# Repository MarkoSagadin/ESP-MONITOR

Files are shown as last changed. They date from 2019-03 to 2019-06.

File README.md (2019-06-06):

# ESP-MONITOR
## ESP8266 based current consumption and serial monitor with Grafana visualization on Raspberry 3 with Node-Red and InfluxDB integration

**ESP-MONITOR** was developed as a student project with help of **IRNAS**, Institute for development of advanced applied systems. You can learn more about them on their [website](http://www.irnas.eu) or [GitHub](https://github.com/IRNAS) page.

Part of the **ESP-MONITOR** project is also repository for Balena multicontainer setup. It can be found [here](https://github.com/SkobecSlo/ESP-MONITOR_balena_setup).
     
### Content
- [Introduction](#Introduction)
- [Preparing the development enviroment](#Preparing-development-enviroment)
- [Overview and setup of ESP-MONITOR](#Overview-and-setup-of-ESP-MONITOR)
- [Setup Raspberry Pi with Balena ](#Setup-raspberry-pi-with-Balena) 
- [Push code to Raspberry](#Push-Raspberry-with-code)
- [Create Influxdb database](#Create-Influxdb-database)
- [Setup Node-Red](#Setup-Node-Red)
- [Setup Grafana](#Setup-Grafana)
- [Resources](#Resources)

###  Introduction 
Often we want to monitor current consumption of our devices. We usually want to do this over a longer periods of time. Maybe we are unsure how some tasks will impact our current consumption and also if our devices really go into sleep mode for periods of time that we intend. At the same time we migh want to catch any serial debug data that our device outputs.

### Perfect job for ESP-MONITOR!
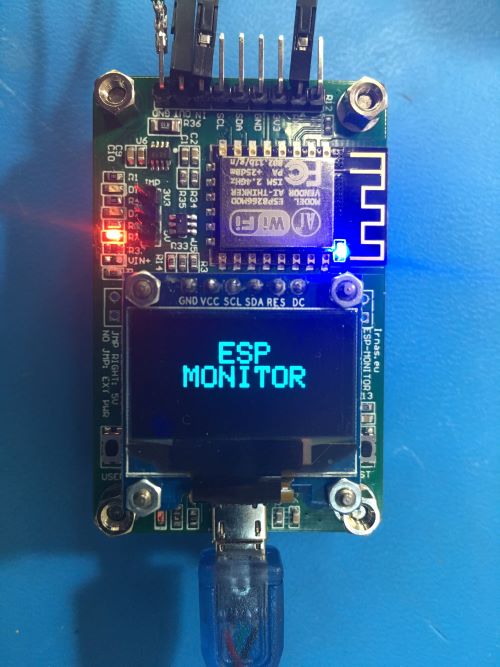
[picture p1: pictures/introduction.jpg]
Introduction


**ESP-MONITOR** is a device that is measuring current consumption and voltage on the device you are monitoring. At the same time it is listening for messages over UART serial connection.
When enough samples are made, we use them to calculate maximum, minimum and average values and standard deviation. 
This values and any received serial messages are then send as a **MQTT** message  to our Raspberry which with help of **Node-RED** parses and prepares our messages to save them into **Influxdb** database.
**Grafana** is then reading the database and displaying the data. 
It is possible to have several of **ESP-MONITOR** devices devices running at the same time and displaying the collected data in **Grafana**. 
That way we can see if several of our monitored devices are behaving as expected. 

###  Preparing the development environment

Download or clone the whole repository from Github.

Use command: `git clone https://github.com/SkobecSlo/ESP-MONITOR.git` in git bash. 

To compile and upload code to our ESP-MONITOR we will need [Visual Studio Code](https://code.visualstudio.com) with **PlatformIO** extension. 
**Visual Studio Code** is a source-code editor developed by Microsoft for Windows, Linux and macOS. It includes support for debugging, embedded Git control, syntax highlighting, intelligent code completion, snippets, and code refactoring.
**PlatformIO** is an open source ecosystem for IoT development. It enables you to quickly install all tools, compilers, basically everything that is needed to quickly start programming your favorite device.
After you install Visual Studio Code, you head to **Extensions** tab (found on left sidebar) and search for **PlatformIO IDE
** in Marketplace search bar. Click install and reload Visual Studio Code to enable newly added plugin. PlatformIO's logo will be added to the left sidebar. 

There are several Arduino libraries that ESP-MONITOR depends on which will have to be installed through PlatformIO. 
Go to PlatformIO -> PIO Home -> Libraries. Search and install following libraries:
- Adafruit_SSD1306 by Adafruit
- Adafruit_GFX by Adafruit
- PubSubClient by Nick O'Leary
- INA219 by DeCristofaro John (when clicked you will see by by gandy92, that is ok)

Adafruits libraries are used for interacting with OLED display over I2C, PuBSubClient is used for MQTT comunication and INA219 is used for interacting with INA219 current monitor over I2C. 

After all libraries are installed go to *File -> Add File to Workspace* and select folder ESP-MONITOR_CODE. To check if everything is ok build the code by clicking **PlatformIO: Build** button on the left side of blue bar at the bottom of Visual Studio Code. 

###  Overview and setup of ESP-MONITOR
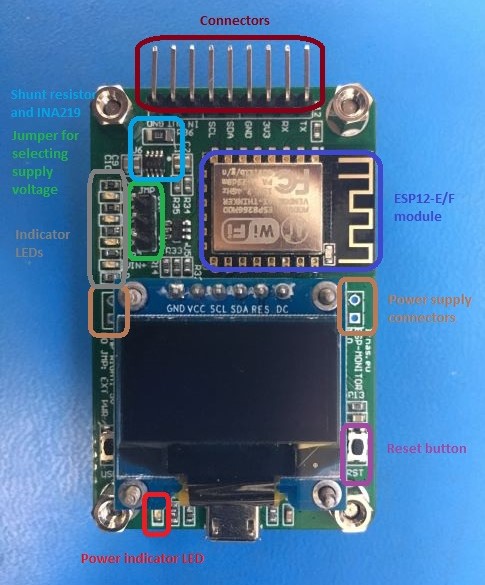
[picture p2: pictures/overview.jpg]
Overview


The heart of ESP-MONITOR is Espressif ESP8266 chip running Arduino enviroment. Code is uploaded over USB connector with help of USB to Serial converter CP2102. The upload setup is similiar to the setup that is used on **NodeMcu** and official development kits boards by **Espressif**. 

#### Short description of PCB elements
**Connectors:** At the top of the board you can find RX pin on which the monitor listens for serial data, TX pin is also exposed for those that want to add extra functionality to the module for comunication with monitored device. Exposed are also 3V3 and GND as well the I2C pins. These can be used to add any extra functionality to the **ESP-MONITOR**. Finally there are also currentmonitor pins IN and OUT. Their role is described below. 

**Power supply connectors:** They are used for chaining several of **ESP-MONITORs** together so that they run from the same power supply. 

**Power indicator LED:** If **ESP-MONITOR** is connected to power supply led will be on, simple as that.  

**Reset buton:** It resets ESP12-E/F module.  

**User button:** It clears flash memory in case if user does not want to use current network which is still reachable. 

**Jumper:** Can be used to connect 3V3 or 5V to the IN pin internally, so that monitored device can function directly from **ESP-MONITOR**. Detailed explantation can be found below. 

**Indicator LEDs:** LED D1 and D2 are controled by ESP module, D1 blinks everytime when current and voltage measuremnts are sent over mqtt. RX LED is connected directly to RX pin. VIN+ LED is connected to IN pin. **WARNING!!** If using higher supply voltages than 5V on IN pin, either **desolder** VIN+ LED off the board or change current limiting resistor R3, otherwise there is gonna be some burning smell.  

#### OLED display configuration

**ESP-MONITOR** is designed in that way that you can connected three different OLED displays (that are usually found on Ebay or AliExpress) to it. The difference is ony in the setup of 0 ohm resistors that are labeled with letters A, B and C under the display. Follow the bottom instructions to determine which resistors are soldered and which ones not, depending on the version of the OLED display.

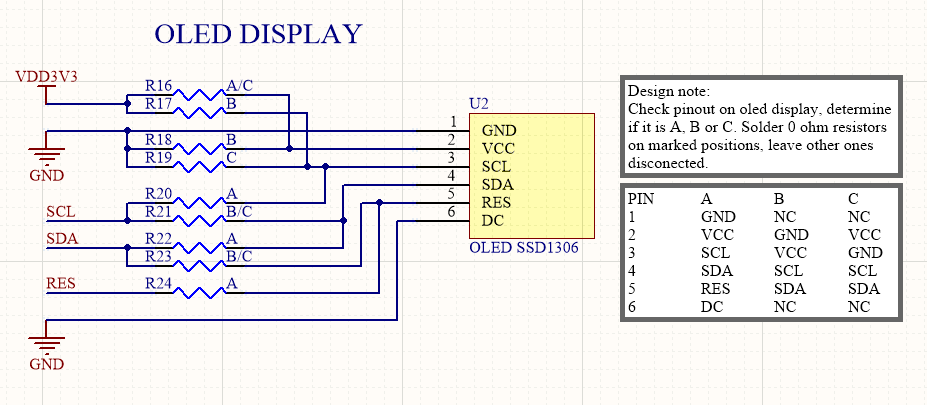
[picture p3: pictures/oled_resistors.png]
oled_resistors


#### Serial data connection
To listen to your serial data of monitored device connect TX output from your device to the RX pin of **ESP-MONITOR**.

#### Current measuring

There are two ways to setup current measuring with **ESP-MONITOR**, either measured device is self powered or we power it from **ESP-MONITOR**.

**Self powered setup**

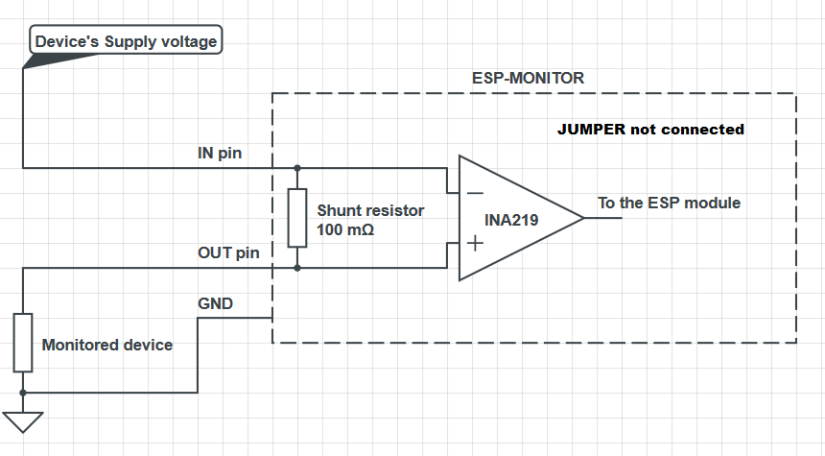
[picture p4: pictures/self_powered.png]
Self_powered


Power is supplied only from monitored device, before connecting IN and OUT pins first connect GND. Jumper is not connected!

**ESP-MONITOR powered setup**

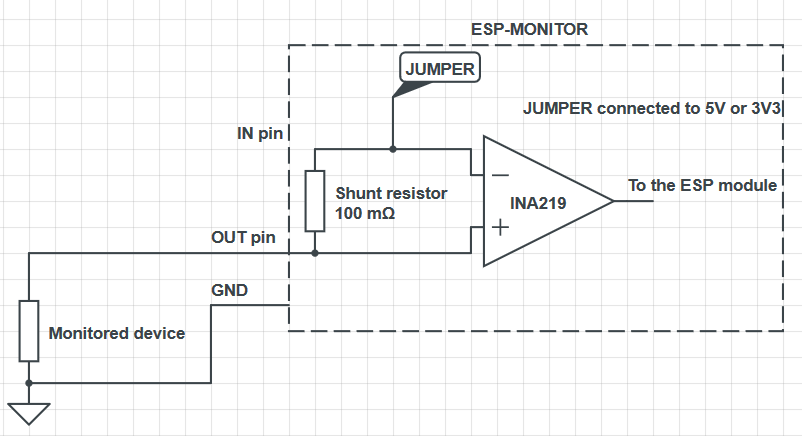
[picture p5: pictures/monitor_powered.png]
monitor_powered


**ESP-MONITOR** is supplying the power. Jumper is connected to 3V3 or 5V. To connect either of this voltages to IN line we have to enable it with Power Cycle pin in Node-Red dashboard. This will be described below.

### Uploading the code and setting the WIFI connection

1. Connect **ESP-MONITOR** with USB to computer and upload the code by clicking **PlatformIO: Upload** button on the left side of blue bar at the bottom of Visual Studio Code. 
2. **ESP-MONITOR's** display should turn on and greet you.
3. Follow instructions on the display: connect with the phone or PC to WIFI network ESP-MONITOR (password is also ESP-MONITOR).
4. Open browser and write IP address 192.168.4.1 in URL field. You will see all nearby wifi networks. Chose one which **ESP-MONITOR** and **Raspberry Pi** will use and connect to it.
5. Reset the module with RESET button, **ESP-MONITOR** should connect to the chosen network. If not, repeat the process. 
  
###  Setup Raspberry Pi with Balena

Balena is an infrastructure for developing, deploying, and managing connected devices at scale. It basically enables you to take an embedded device (or devices) with Linux OS and control or update their firmware over air. 

Steps to get Raspberry Pi running with Balena
1. Create an account on [Balena](https://www.balena.io)
2. Follow instructions on Balena's get started [web page](https://www.balena.io/docs/learn/getting-started/raspberrypi3/nodejs/) untill the start of chapter **Deploy Code**.
3. Make sure that you download the correct and latest image for Raspberry Pi 3.
4. Make sure that under Network option you check Wifi + Ethernet and that Wifi ssid and passphrase are the same as the one you used to connect **ESP-MONITOR** to.   

###  Push code to Raspberry 

Open git bash in folder of your choice and write:
1. `git clone https://github.com/SkobecSlo/ESP-MONITOR_balena_setup.git`
2. `cd ESP-MONITOR_balena_setup`
3. Go to your Balena application dashboard and click copy to clip board button and paste it into git bash
git_remote
4. `git push balena master`

The last command will upload the whole repository first to the Balena servers which will compile them and then upload them to the Raspberry. In case of successfull event you will see Balena Unicorn in git bash. 

###  Create Influx database

Before continuing to our Node-Red flows, we have to setup our database in which we will be saving data into. 
Go to the application dashboard of your device and click its name. This link will take you to the dashboard of that specific device. Here you can see status of your device, if it is online, offline, updating, ect. 
After making sure that device is updated with our code click inside Terminal window a **select a target** button and select **influxdb** option. This action will make a SHH connection to our Influxdb container. Type `Influxdb` and then following command: `create database Monitor`

This will create exactly what it says. Use exactly that case sensitive name, as it is the name that **Grafana** expects. Close the connection. 

###  Setup Node-Red  

1. Enable public device URL and click blue button that will appear next to it.
2. This will take you to the **Grafana** login page, which we dont need yet.
3. In Url box of the browser delete /login from the end of URL and replace it with /node-red
4. This will take you to the configuration page of **Node-Red**
5. Username and password are **admin**
6. Locate node-red-flow.txt file in node-red-setup folder
7. Copy its content and locate in Node-Red *Menu -> Import -> Clipboard* option and paste it there.

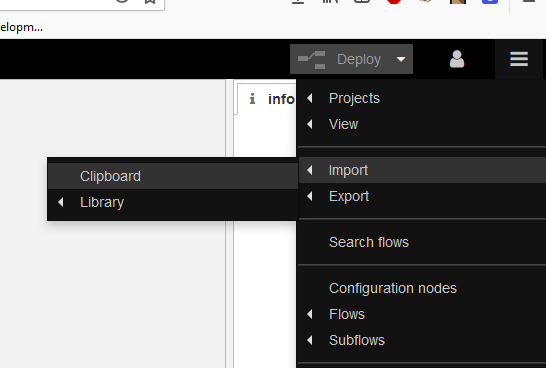
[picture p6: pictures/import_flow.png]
import_flow


This is a basic default flow configuration. There are some parameters that are device specific and need to be changed to work with your Raspberry Pi:
- Click one of the purple mqtt nodes in Node-Red and make sure that the IP address of the server is the same as the IP address of your device which can be found on device's Balena dashboard. Port stays 1883. Check all other purple nodes if they have correct setup.

That is it, you can now click Deploy button at top. Mqtt nodes should have green dot with connected label next to them. 

If you add to the end of public url **/node-red/ui** you will arrive at Node-Red dashboard, where you can see most recent serial output, most recent raw measurement and a Power Cycle switch which will control voltage on IN pin if jumper is connected to either 3V3 or 5V. 

###  Setup Grafana  

1. Go to your public device url now and login into Grafana with username: **admin** and password **admin**. 
2. Click *Gear icon -> Data sources* 
3. Click big icon with Monitor title and Influxdb logo.
4. All details should be filled in, scroll down and click save and test button. If everything is ok you will get conformation message.
5. Go back to main menu and click *Home* button and under general choose *Current consumption*.  

Now you are in the main dashboard that is showing all data that **ESP-MONITOR** is collecting. To make data actually appear you have to setup each one of the windows to your deviceID tag that is specific for each **ESP-MONITOR**. 
1. Click at the top of one of the windows and chose edit option. Click one of the lines under the Metrics tab and click field next to deviceID equal sign.
2. It should show you the id that is showed on OLED display of **ESP-MONITOR**, select it.
3. Do this for each line, for each graph, table in Grafana dashboard. 
4. You should see data that **ESP-MONITOR** collected.
  
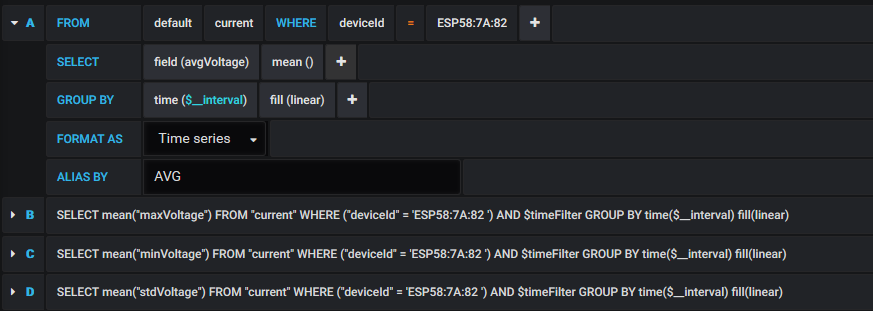
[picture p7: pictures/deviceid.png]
deviceid

#### Specific strings setup

Node-Red is already saving all serial data into InfluxDB and Grafan is already displaying them as timetable. If you want to monitor for specific string and represent it in a graph do following:
1. Navigate to Node-Red and click on Messages node
2. Here you can add specific string that you are looking for 
3. Select **contains** option and in the field write your string
4. You can add more of them by clicking add button on the bottom, this will add more outputs to the node.
5. Each output fill have to go through separate **Notification string** node before going into **Specific strings** INfluxdb node. 
6. Modify this field in each separate **Notification string** node to your liking, it can be the same as the specific stirng you are searching for. Deploy changes 
7. These fields are tags that Grafana uses to present data. 
8. Go to Grafana and create or edit existing graph.
9. Metrics tab should look something like picture below, you have to change devices id to yours and also notificationField to the string that you used in Node-Red.

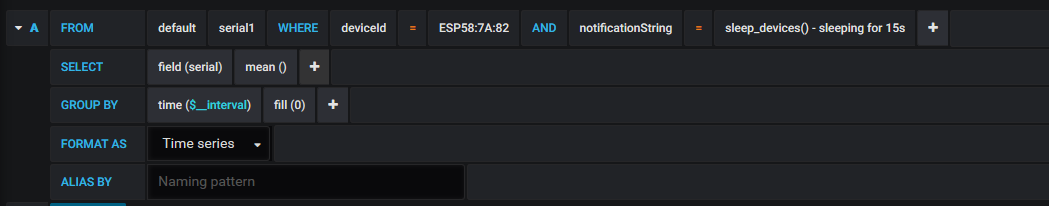
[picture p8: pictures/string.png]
string


###  Resources 

Here are some resources that helped me on my way of developing the project:
- [ESP-LINK](https://github.com/jeelabs/esp-link) 
- [Balena Sense](https://github.com/balena-io-playground/balena-sensehat-example)
- [Multicontainer Balena example with 8 containers](https://github.com/janvda/balena-node-red-mqtt-nginx-TIG-stack)
- [Provisioned dashboards for Grafana](https://ops.tips/blog/initialize-grafana-with-preconfigured-dashboards)
- [Andreas Spiess's video on Node-Red, Influxdb and Grafana](https://www.youtube.com/watch?v=JdV4x925au0)

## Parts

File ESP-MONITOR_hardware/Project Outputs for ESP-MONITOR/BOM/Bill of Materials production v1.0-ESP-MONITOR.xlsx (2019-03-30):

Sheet: Part List Report
 | Component list |  |  | ESP-MONITOR
 | Source Data From: | ESP-MONITOR.PrjPCB |  |  | Contact:
 | Project: | ESP-MONITOR.PrjPCB
 | Variant: | None |  |  |  |  |  |  | IRNAS
 | Report Date: | 2019-12-03 | 10:47:00 |  |  |  |  |  | www.irnas.eu
 | Print Date: | 2019-03-12 | 10:48:11
# | Manufacturer Part Number 1 | Manufacturer 1 | Description | Footprint | Designator | Quantity | Supplier 1 | Supplier Part Number 1 | Supplier Order Qty 1 | Supplier Stock 1 | Supplier Unit Price 1 | Supplier Subtotal 1 | Supplier Currency 1
1 | GRM188R61H105KAALD | Murata | MURATA - GRM188R61H105KAALD - CAP, MLCC, X5R, 1UF, 50V, 0603 | CAP0603 | C1, C9 | 2 | Farnell | 1845736 | 10 | 0 | 0.35 | 3.51 | GBP
2 | GRM188R71C104KA01J | Murata | MURATA - GRM188R71C104KA01J - CAP, MLCC, X7R, 0.1UF, 16V, 0603 | CAP0603 | C2, C3, C8, C10 | 4 | Farnell | 2688519 | 10 | 0 | 0.02 | 0.21 | EUR
3 | CGA4J1X5R1C106K125AC | TDK | TDK - CGA4J1X5R1C106K125AC - CAP, MLCC, X5R, 10UF, 16V, 0805 | CAP0805 | C4, C5, C7 | 3 | Farnell | 2210948RL | 150 | 0 | 0.24 | 36.00 | GBP
4 | MCSH18B101K500CT | Multicomp | MULTICOMP MCSH18B101K500CT SMD Multilayer Ceramic Capacitor, MCSH Series, 100 pF, 10%, X7R, 50 V, 0603 [1608 Metric] | CAP0603 | C6 | 1 | Farnell | 1856366 | 10 | 18461 | 0.05 | 0.49 | GBP
5 |  |  |  | microUSB-CHINA | CON2 | 1
6 | HSMS-C190 | Broadcom | BROADCOM LIMITED - HSMS-C190 - LED, RED, 10MCD, 626NM | LED0603 | D1, D2, D5, RX, VIN+ | 5 | Farnell | 2497356 | 10 | 0 | 0.12 | 1.24 | GBP
7 | MBR120VLSFT3G | ON Semiconductor | ON SEMICONDUCTOR - MBR120VLSFT3G - SCHOTTKY RECT, 1A, 20V, SOD123 | SOD123 | D4 | 1 | Farnell | 2533227 | 5 | 60691 | 0.26 | 1.31 | GBP
8 | 0603L035YR | Littelfuse | LITTELFUSE - 0603L035YR - RESETTABLE FUSE, PTC, 40A, 6V, 0605 | FUSE0603 | F3 | 1 | Farnell | 1832099 | 10 | 3378 | 1.28 | 12.80 | GBP
9 |  |  | Jumper_1x3 | Jumper_1x3_2.54MM | J4 | 1
10 |  |  | Header, 2-Pin | HDR1X2 | P1, P3, P4 | 3
11 |  |  | Header, 4-Pin | HDR1X4 | P2 | 1
12 |  |  | Header, 3-Pin | HDR1X3 | P5 | 1
13 | MCMR06X471JTL | Multicomp | MULTICOMP - MCMR06X471 JTL - RES, CERAMIC, 470R, 5%, 0.1W, 0603 | RES0603 | R1, R4, R8, R26, R37 | 5 | Farnell | 2073513 | 10 | 0 | 0.01 | 0.06 | EUR
14 | MCMR06X4701FTL | Multicomp | MULTICOMP - MCMR06X4701FTL - RES, CERAMIC, 4K7, 1%, 0.1W, 0603 | RES0603 | R2, R3 | 2 | Farnell | 2073509 | 10 | 27151 | 0.01 | 0.09 | GBP
15 | CR0603-J/-000ELF | Bourns | BOURNS - CR0603-J/-000ELF - RES, THICK FILM, 0R, 5%, 0.1W, 0603 | RES0603 | R5, R6, R16, R17, R18, R19, R20, R21, R22, R23, R24, R25, R27 | 13 | Farnell | 2008343 | 26 | 46345 | 0.01 | 0.31 | GBP
16 | MCMR06X103JTL | Multicomp | MULTICOMP - MCMR06X103 JTL - RES, CERAMIC, 10K, 5%, 0.1W, 0603 | RES0603 | R7, R9, R10, R11, R12, R13, R14, R15, R31 | 9 | Farnell | 2073356 | 18 | 0 | 0.01 | 0.14 | EUR
17 | MCWR06X27R0FTL | Multicomp | MULTICOMP MCWR06X27R0FTL Surface Mount Chip Resistor, Thick Film, MCWR Series, 27 ohm, 100 mW, 1%, 50 V | RES0603 | R28, R29 | 2 | Farnell | 2447316 | 10 | 108261 | 0.01 | 0.05 | GBP
18 | MC0.063W06031%1M | Multicomp | MULTICOMP - MC0063W060311M - RES, THICK FILM, 1M, 1%, 0.063W, 0603 | RES0603 | R30 | 1 | Farnell | 9330410 | 10 | 0 | 0.07 | 0.69 | GBP
19 | MCMR06X104JTL | Multicomp | MULTICOMP - MCMR06X104 JTL - RES, CERAMIC, 100K, 5%, 0.1W, 0603 | RES0603 | R32, R34 | 2 | Farnell | 2073357 | 10 | 49 | 0.01 | 0.07 | GBP
20 | MC0.063W06031%100R | Multicomp | MULTICOMP - MC0063W06031100R - RES, THICK FILM, 100R, 1%, 0.063W, 0603 | RES0603 | R33, R35 | 2 | Farnell | 9330364 | 10 | 0 | 0.04 | 0.36 | EUR
21 | TL2BR10FTE | TE Connectivity | TE CONNECTIVITY - TL2BR10FTE - RESISTOR, METAL , R10, 0.25W, 1%, 1206 | RES1206 | R36 | 1 | Farnell | 2330389 | 10 | 360 | 0.79 | 7.93 | GBP
22 |  |  | SWITCH TACTILE SPST-NO 0.05A 32V | Tactile button | RST, USER | 2 | C&K Components | 2845727
23 |  |  | ESP-12 Wi-Fi Module by AI-Thinker | ESP_12_E | U1 | 1
24 |  |  |  | OLED SSD1306 | U2 | 1
25 |  |  | NCP1117, NCV1117. 1.0 A Low-Dropout Positive Fixed and Adjustable Voltage Regulators | SOT-223 - 4con | U3 | 1
26 | CP2102N-A01-GQFN28 | Silicon Labs | SILICON LABS CP2102N-A01-GQFN28 Interface Bridges, USB to UART, 3 V, 3.6 V, QFN, 28 Pins, -40 C New | QFN50P500X500X80_HS-29N | U4 | 1 | Farnell | 2577279 | 2 | 0 | 1.46 | 2.92 | EUR
27 | DMG6602SVT | Diodes | DIODES INC. - DMG6602SVT - MOSFET, NP CH, , 30V, 3.4, ATSOT23 | TSOT26 | U5 | 1 | Farnell | 2061522 | 5 | 2033 | 0.24 | 1.20 | EUR
28 | INA219AIDCNR | Texas Instruments | 26V, Bi-Directional, High-Side, I2C Out Current/Power Monitor 8-SOT-23 -40 to 125 | SOT23-8 | U6 | 1 | Farnell | 2295989 | 2 | 13626 | 1.53 | 3.06 | GBP
29 |  |  | Surface mount NPN transistor, package SOT-23 | SMT_TRIODE_NPN | VT1, VT2 | 2
 |  |  |  |  |  | 71 |  |  | 328 |  |  | 72.4404
Approved |  |  |  | Notes
 |  |  |  | pcs: |  | 2 |  | Total |  | 72.4404 |  | EUR
 |  |  |  |  |  |  |  | Price for 1pcs |  | 36.22 |  | EUR

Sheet: Project Information
Project Full Path | C:\Users\MarkoSagadin\Desktop\Irnas\ESP-MONITOR\ESP-MONITOR.PrjPCB
Project Filename | ESP-MONITOR.PrjPCB
Variant Name | None
Data-Source Filename | ESP-MONITOR.PrjPCB
Data-Source Full Path | C:\Users\MarkoSagadin\Desktop\Irnas\ESP-MONITOR\ESP-MONITOR.PrjPCB
Title | Bill of Materials production v1.0 for Project [ESP-MONITOR.PrjPCB] (PCB Document : ESP-MONITOR_PCB.PcbDoc)
Total Quantity | 71
Report Time | 10:47:00
Report Date | 2019-12-03
Report Date & Tine | 2019-12-03 10:47
Output Name | Bill of Materials production v1.0
Output Type | BOM_PartType
Output Generator Name | BOM
Output Generator Description | Bill of Materials

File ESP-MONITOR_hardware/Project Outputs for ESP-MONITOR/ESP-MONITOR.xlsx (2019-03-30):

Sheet: Part List Report
 | Component list |  |  | ESP-MONITOR
 | Source Data From: | ESP-MONITOR.BomDoc |  |  | Contact:
 | Project: | ESP-MONITOR.PrjPCB
 | Variant: | None |  |  |  |  |  |  | IRNAS
 | Report Date: | 2019-12-03 | 14:04:00 |  |  |  |  |  | www.irnas.eu
 | Print Date: | 2019-03-12 | 14:24:54
# | Manufacturer Part Number 1 | Manufacturer 1 | Description | Footprint | Designator | Quantity | Supplier 1 | Supplier Part Number 1 | Supplier Order Qty 1 | Supplier Stock 1 | Supplier Unit Price 1 | Supplier Subtotal 1 | Supplier Currency 1
1 | GRM188R61H105KAALD | Murata | MURATA - GRM188R61H105KAALD - CAP, MLCC, X5R, 1UF, 50V, 0603 | CAP0603 | C1, C9 | 2 | Farnell | 1845736
2 | GRM188R71C104KA01J | Murata | MURATA - GRM188R71C104KA01J - CAP, MLCC, X7R, 0.1UF, 16V, 0603 | CAP0603 | C2, C3, C8, C10 | 4 | Farnell | 2688519
3 | CGA4J1X5R1C106K125AC | TDK | TDK - CGA4J1X5R1C106K125AC - CAP, MLCC, X5R, 10UF, 16V, 0805 | CAP0805 | C4, C5, C7 | 3 | Farnell | 2210948RL
4 | MCSH18B101K500CT | Multicomp | MULTICOMP MCSH18B101K500CT SMD Multilayer Ceramic Capacitor, MCSH Series, 100 pF, 10%, X7R, 50 V, 0603 [1608 Metric] | CAP0603 | C6 | 1 | Farnell | 1856366 | 10 | 18461 | 0.05 | 0.49 | GBP
5 | HSMS-C190 | Broadcom | BROADCOM LIMITED - HSMS-C190 - LED, RED, 10MCD, 626NM | LED0603 | D1, D2, D5, RX, VIN+ | 5 | Farnell | 2497356
6 | MBR120VLSFT3G | ON Semiconductor | ON SEMICONDUCTOR - MBR120VLSFT3G - SCHOTTKY RECT, 1A, 20V, SOD123 | SOD123 | D4 | 1 | Farnell | 2533227 | 5 | 60691 | 0.26 | 1.31 | GBP
7 | 0603L035YR | Littelfuse | LITTELFUSE - 0603L035YR - RESETTABLE FUSE, PTC, 40A, 6V, 0605 | FUSE0603 | F3 | 1 | Farnell | 1832099 | 10 | 3378 | 1.28 | 12.80 | GBP
8 | MCMR06X471JTL | Multicomp | MULTICOMP - MCMR06X471 JTL - RES, CERAMIC, 470R, 5%, 0.1W, 0603 | RES0603 | R1, R4, R8, R26, R37 | 5 | Farnell | 2073513
9 | MCMR06X4701FTL | Multicomp | MULTICOMP - MCMR06X4701FTL - RES, CERAMIC, 4K7, 1%, 0.1W, 0603 | RES0603 | R2, R3 | 2 | Farnell | 2073509 | 10 | 27151 | 0.01 | 0.09 | GBP
10 | CR0603-J/-000ELF | Bourns | BOURNS - CR0603-J/-000ELF - RES, THICK FILM, 0R, 5%, 0.1W, 0603 | RES0603 | R5, R6, R16, R17, R18, R19, R20, R21, R22, R23, R24, R25, R27 | 13 | Farnell | 2008343 | 26 | 46345 | 0.01 | 0.31 | GBP
11 | MCMR06X103JTL | Multicomp | MULTICOMP - MCMR06X103 JTL - RES, CERAMIC, 10K, 5%, 0.1W, 0603 | RES0603 | R7, R9, R10, R11, R12, R13, R14, R15, R31 | 9 | Farnell | 2073356
12 | MCWR06X27R0FTL | Multicomp | MULTICOMP MCWR06X27R0FTL Surface Mount Chip Resistor, Thick Film, MCWR Series, 27 ohm, 100 mW, 1%, 50 V | RES0603 | R28, R29 | 2 | Farnell | 2447316 | 10 | 108261 | 0.01 | 0.05 | GBP
13 | MC0.063W06031%1M | Multicomp | MULTICOMP - MC0063W060311M - RES, THICK FILM, 1M, 1%, 0.063W, 0603 | RES0603 | R30 | 1 | Farnell | 9330410
14 | MCMR06X104JTL | Multicomp | MULTICOMP - MCMR06X104 JTL - RES, CERAMIC, 100K, 5%, 0.1W, 0603 | RES0603 | R32, R34 | 2 | Farnell | 2073357 | 10 | 49 | 0.01 | 0.07 | GBP
15 | MC0.063W06031%100R | Multicomp | MULTICOMP - MC0063W06031100R - RES, THICK FILM, 100R, 1%, 0.063W, 0603 | RES0603 | R33, R35 | 2 | Farnell | 9330364
16 | TL2BR10FTE | TE Connectivity | TE CONNECTIVITY - TL2BR10FTE - RESISTOR, METAL , R10, 0.25W, 1%, 1206 | RES1206 | R36 | 1 | Farnell | 2330389 | 10 | 360 | 0.79 | 7.93 | GBP
17 | KMR221NG LFS | C&K Components | SWITCH TACTILE SPST-NO 0.05A 32V | Tactile button | RST, USER | 2 | Farnell | 2845727 | 10 | 2708 | 0.29 | 2.90 | GBP
18 |  |  | ESP-12 Wi-Fi Module by AI-Thinker | ESP_12_E | U1 | 1
19 |  |  |  | OLED SSD1306 | U2 | 1
20 | NCP1117ST33T3G | ON Semiconductor | NCP1117ST33T3G - Fixed LDO Voltage Regulator, 3.5V to 20V, 1.07V Dropout, 3.3Vout, 1Aout, SOT-223-3 | SOT-223 | U3 | 1 | Farnell | 1652366 | 5 | 143571 | 0.33 | 1.64 | GBP
21 | CP2102N-A01-GQFN28 | Silicon Labs | SILICON LABS CP2102N-A01-GQFN28 Interface Bridges, USB to UART, 3 V, 3.6 V, QFN, 28 Pins, -40 C New | QFN50P500X500X80_HS-29N | U4 | 1 | Digi-key | 336-3694-ND | 5 | 5052 | 1.22 | 6.10 | EUR
22 | DMG6602SVT | Diodes | DIODES INC. - DMG6602SVT - MOSFET, NP CH, , 30V, 3.4, ATSOT23 | TSOT26 | U5 | 1 | Farnell | 2061522 | 5 | 2033 | 0.24 | 1.20 | EUR
23 | INA219AIDCNR | Texas Instruments | 26V, Bi-Directional, High-Side, I2C Out Current/Power Monitor 8-SOT-23 -40 to 125 | SOT23-8 | U6 | 1 | Farnell | 2295989 | 2 | 13626 | 1.53 | 3.06 | GBP
24 | BC817,215 | Nexperia | BC817,215 - Bipolar (BJT) Single Transistor, General Purpose, NPN, 45 V, 100 MHz, 250 mW, 500 mA, 100 hFE | SMT_TRIODE_NPN | VT1, VT2 | 2 | Farnell | 1081223 | 5 | 183983 | 0.13 | 0.64 | EUR
 |  |  |  |  |  | 64 |  |  | 123 |  |  | 38.5864
Approved |  |  |  | Notes
 |  |  |  | pcs: |  | 2 |  | Total |  | 38.5864 |  | EUR
 |  |  |  |  |  |  |  | Price for 1pcs |  | 19.29 |  | EUR

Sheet: Project Information
Project Full Path | C:\Users\MarkoSagadin\Desktop\Irnas\ESP-MONITOR\ESP-MONITOR.PrjPCB
Project Filename | ESP-MONITOR.PrjPCB
Variant Name | None
Data-Source Filename | ESP-MONITOR.BomDoc
Data-Source Full Path | C:\Users\MarkoSagadin\Desktop\Irnas\ESP-MONITOR\ESP-MONITOR.BomDoc
Title | Bill of Materials production v1.0 for BOM Document [ESP-MONITOR.BomDoc]
Total Quantity | 64
Report Time | 14:04:00
Report Date | 2019-12-03
Report Date & Tine | 2019-12-03 14:04
Output Name | Bill of Materials production v1.0
Output Type | BOM_PartType
Output Generator Name | BOM
Output Generator Description | Bill of Materials

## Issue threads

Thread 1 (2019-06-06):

Powercycle jumper [hardware/software]

MarkoSagadin, 2019-06-06:
Jumper should be three way: it should connect 3.3V or 5V to VIN+ of INA219 and also IN input pin. With this setup will be possible to turn on and off monitored device from Node-Red Dashboard no matter if device is self powered or powered by ESP-MONITOR.
Also change Powercylce Button to be normally on at initialization: in firmware and Node-Red.

Closed 2022-03-04.

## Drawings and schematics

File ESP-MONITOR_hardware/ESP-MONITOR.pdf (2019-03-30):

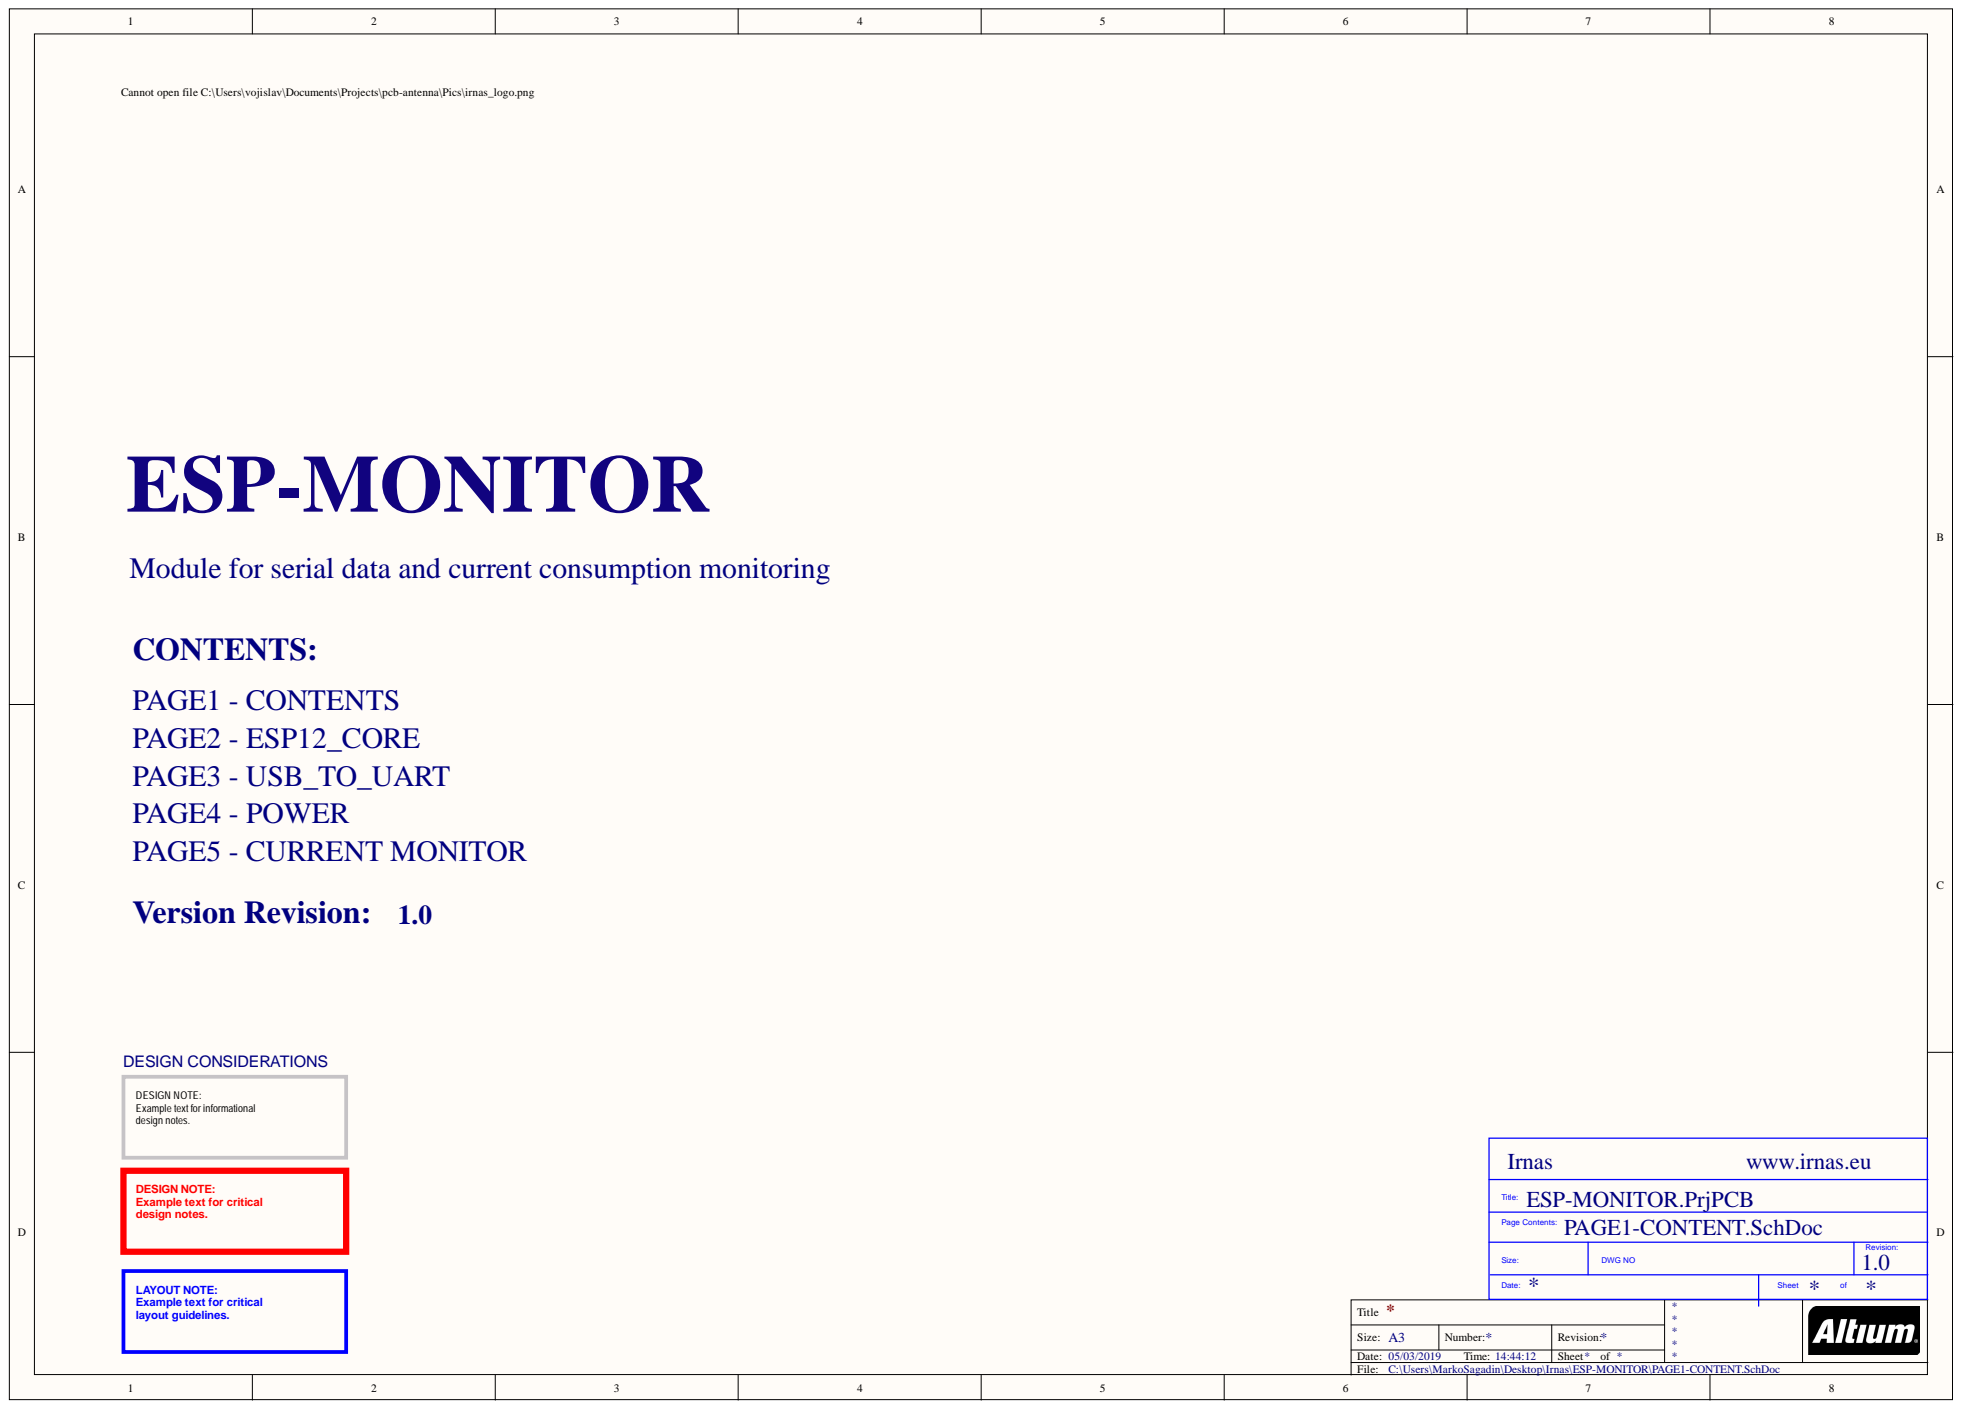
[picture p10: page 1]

Cannot open file C:\Users\vojislav\Documents\Projects\pcb-antenna\Pics\irnas_logo.png

Module for serial data and current consumption monitoring

DESIGN NOTE:
Example text for informational
design notes.

Example text for critical

LAYOUT NOTE:
layout guidelines.

Title | *

Size: A3 | Number: | Revision:
Date: 05/03/2019 Time: 14:44:12 | | Sheet * of *

C:\Users\MarkoSagadin\Desktop\Irnas\ESP-MONITOR\PAGE1-CONTENT.SchDoc

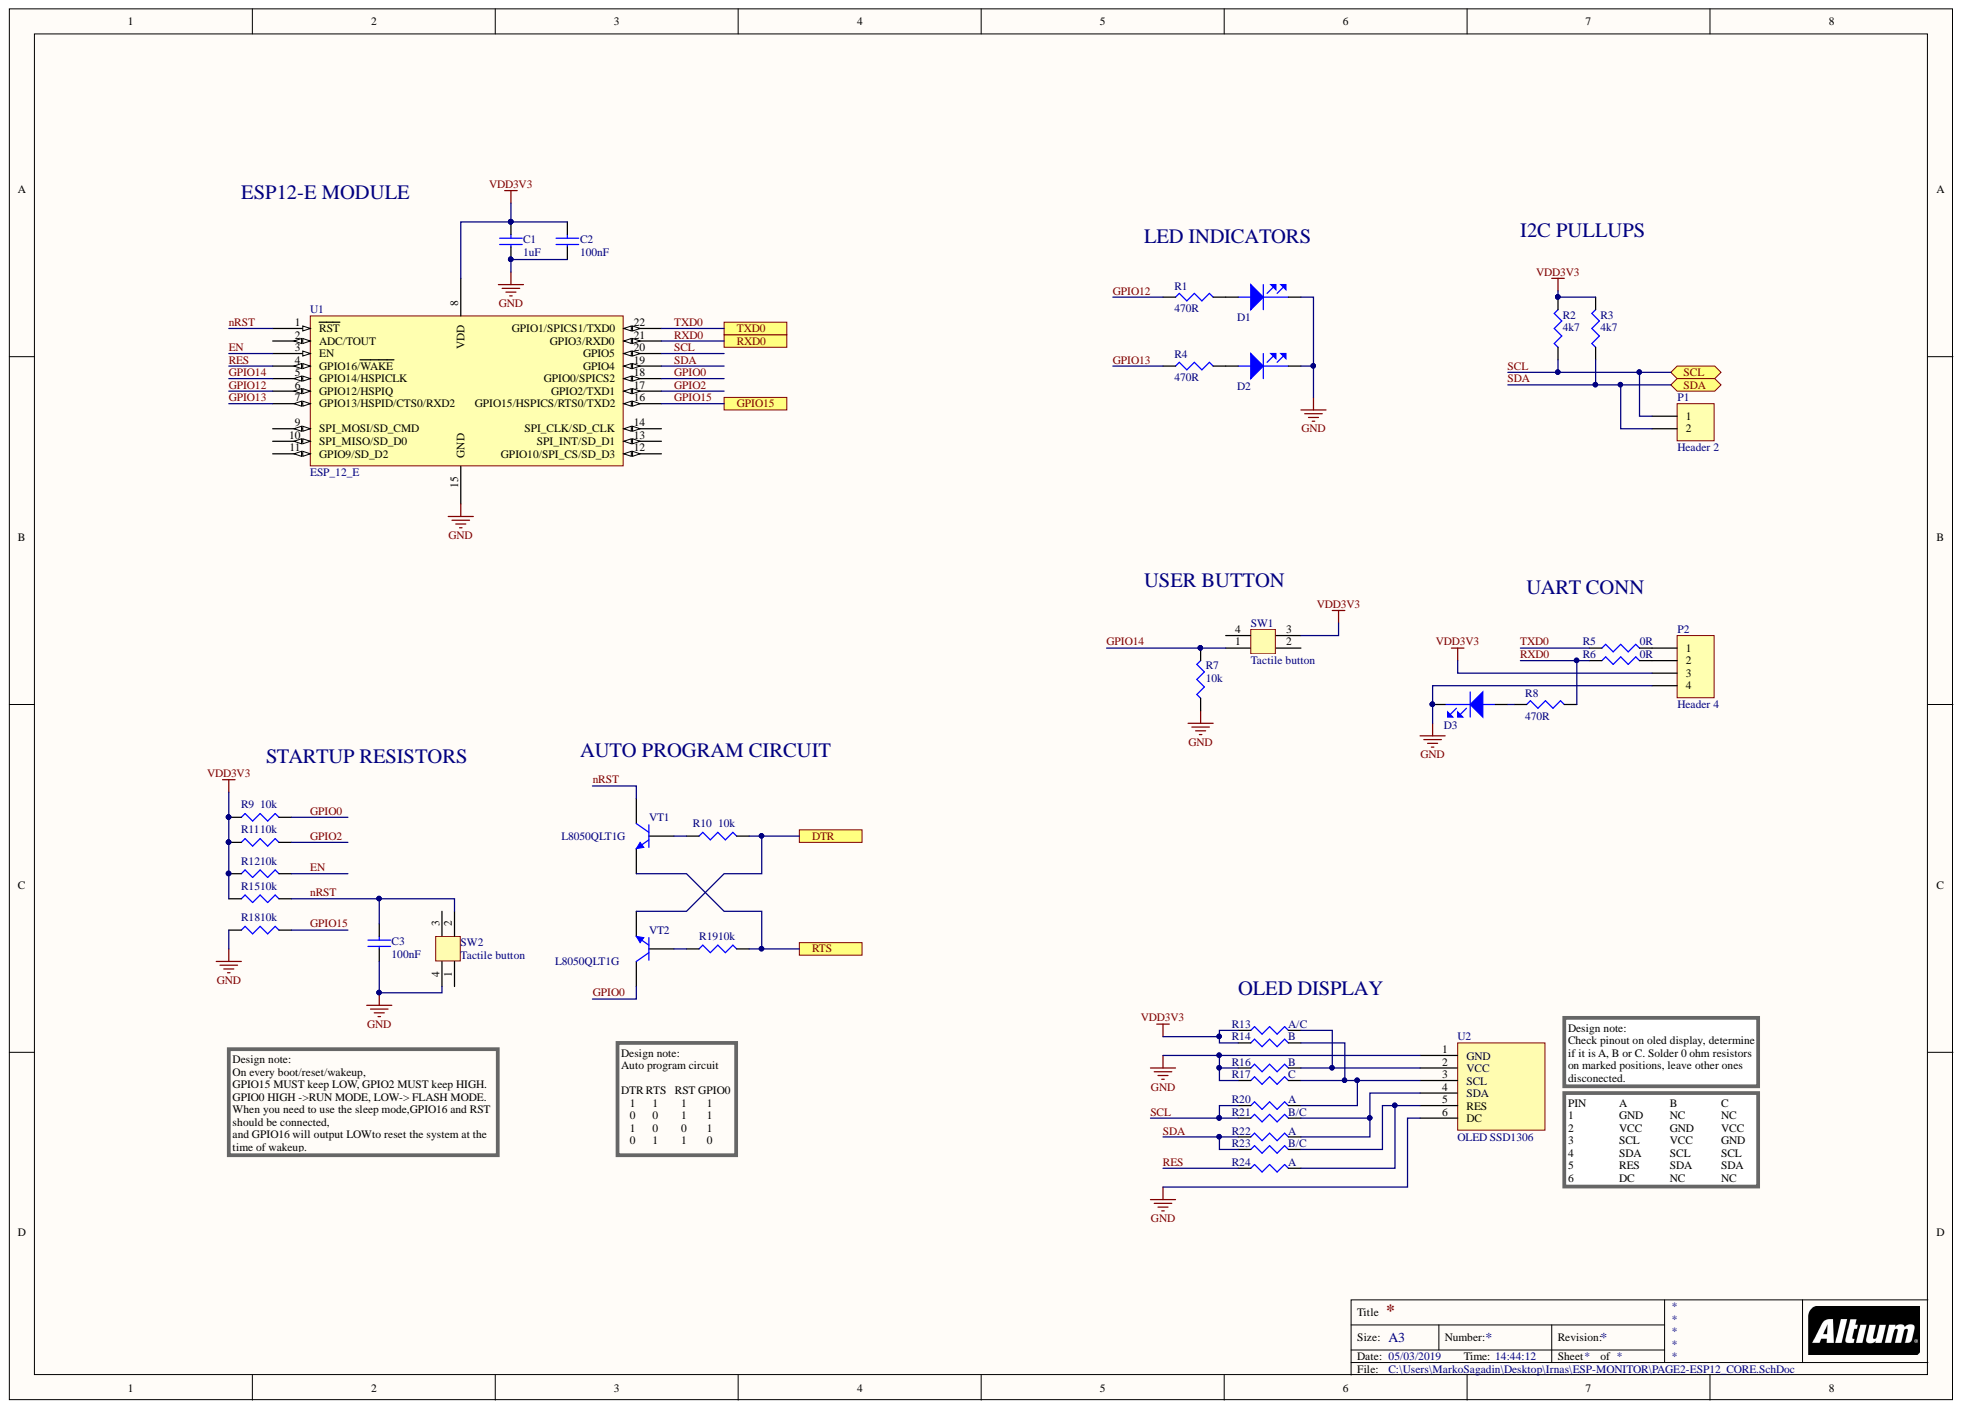
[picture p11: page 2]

Des
Check pinout on oled di
on marked pos

A, B or C. Solder 0 ohm res

ions, leave other ones

When you need to use the s
should be connected,
and GPI

OWto reset the sys

Size: A | Number : | Revi s ion:

Ti me: | | Sheet of

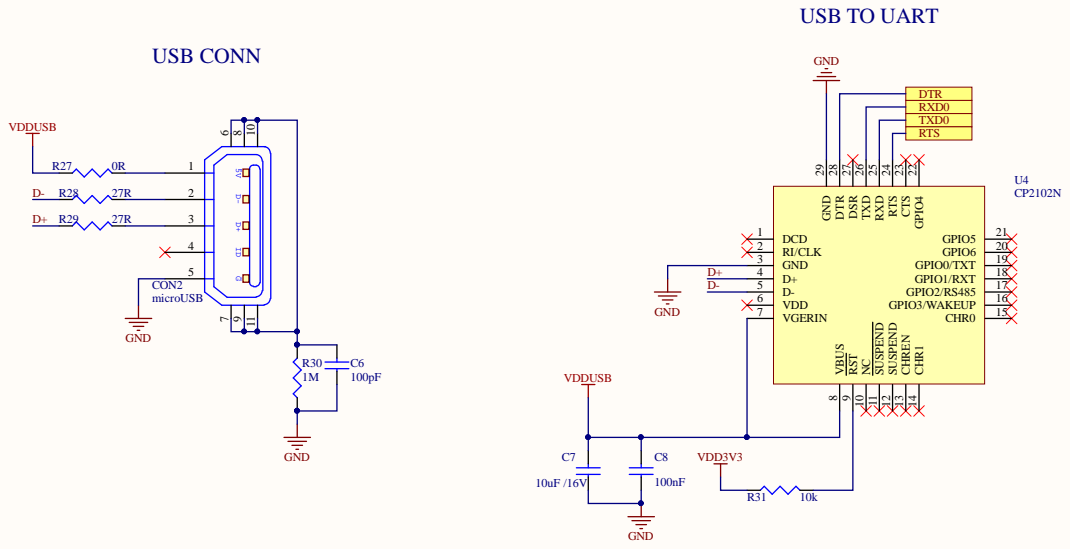
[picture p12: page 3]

GPIO4 22 CTS 23 RTS 24 RXD 25 TXD 26 DSR 27 DTR 28 GND 29

Size: A | Number : | Revi s ion:

Ti me: | | Sheet of

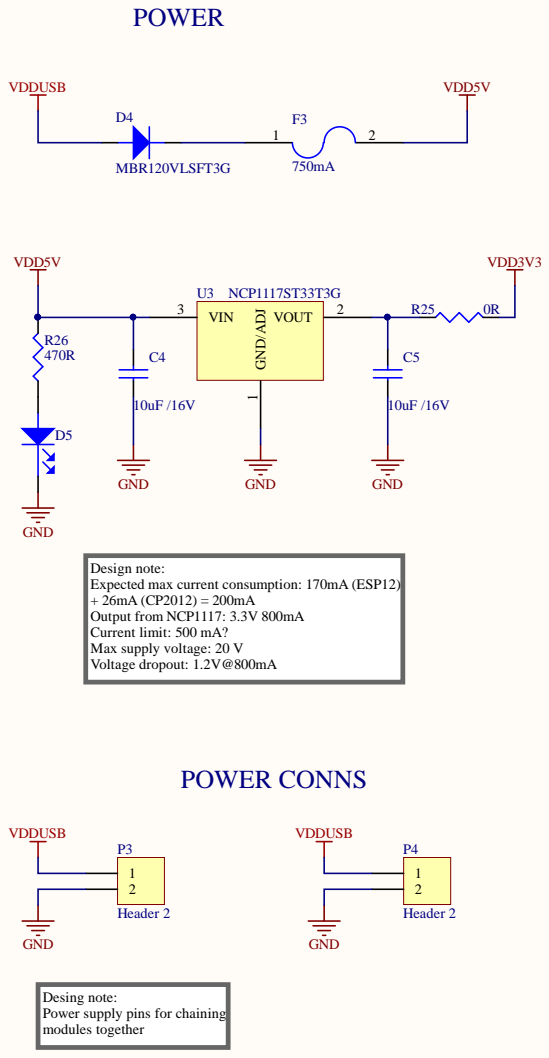
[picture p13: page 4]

Design note:
Expected max current consumption: 170mA (ESP12)
Output from NCP1117: 3.3V 800mA
Current limit: 500 mA?
Max supply voltage: 20 V
Voltage dropout: 1.2V@800mA

Desing note:
Power supply pins for chaining
modules together

C:\Users\MarkoSagadin\Desktop\Irnas\ESP-MONITOR\PAGE4-POWER.SchDoc

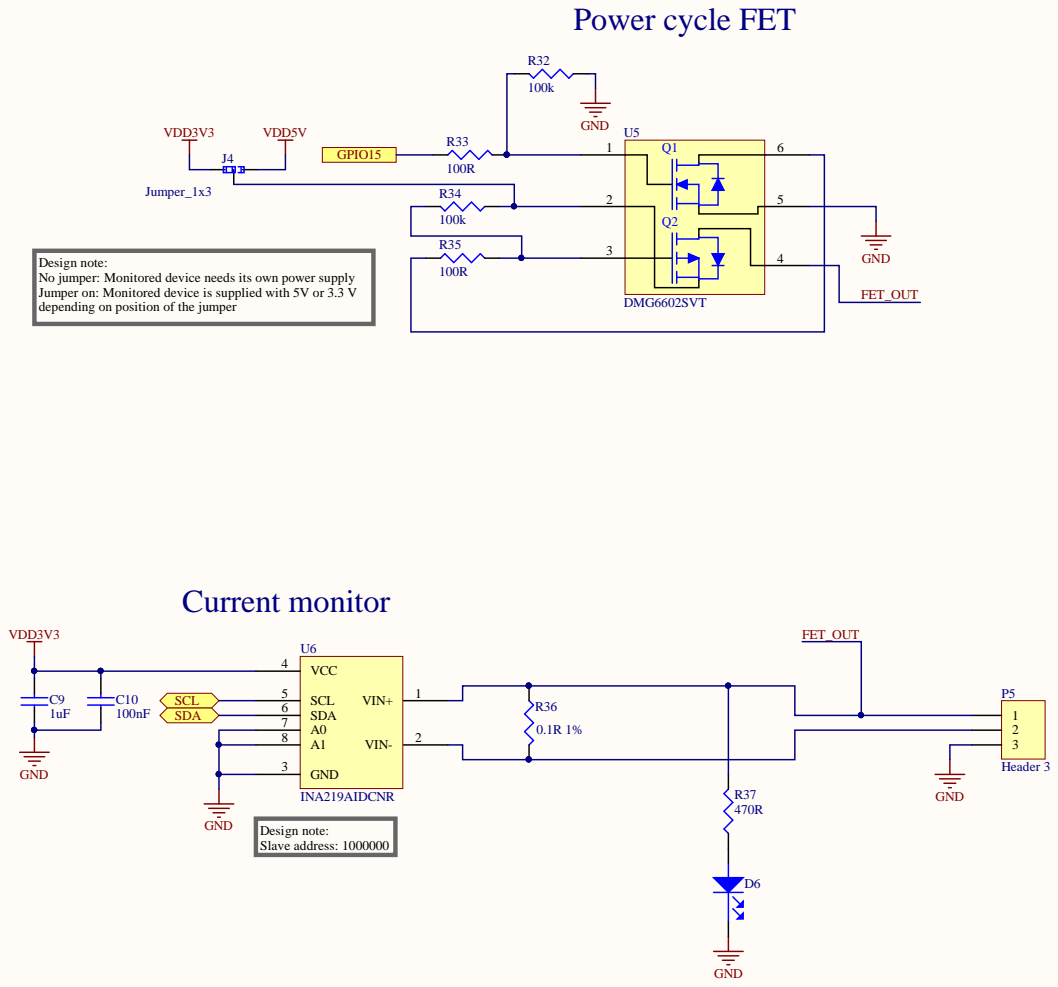
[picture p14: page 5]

GPIO15 | 5

Design note:
No jumper: Monitored device needs its own power supply
Jumper on: Monitored device is supplied with 5V or 3.3 V
depending on position of the jumper

FET_OUT

A0 7
A1 8

GND 3

C:\Users\MarkoSagadin\Desktop\Irnas\ESP-MONITOR\PAGE5-CURRENT_MONITOR.SchDoc

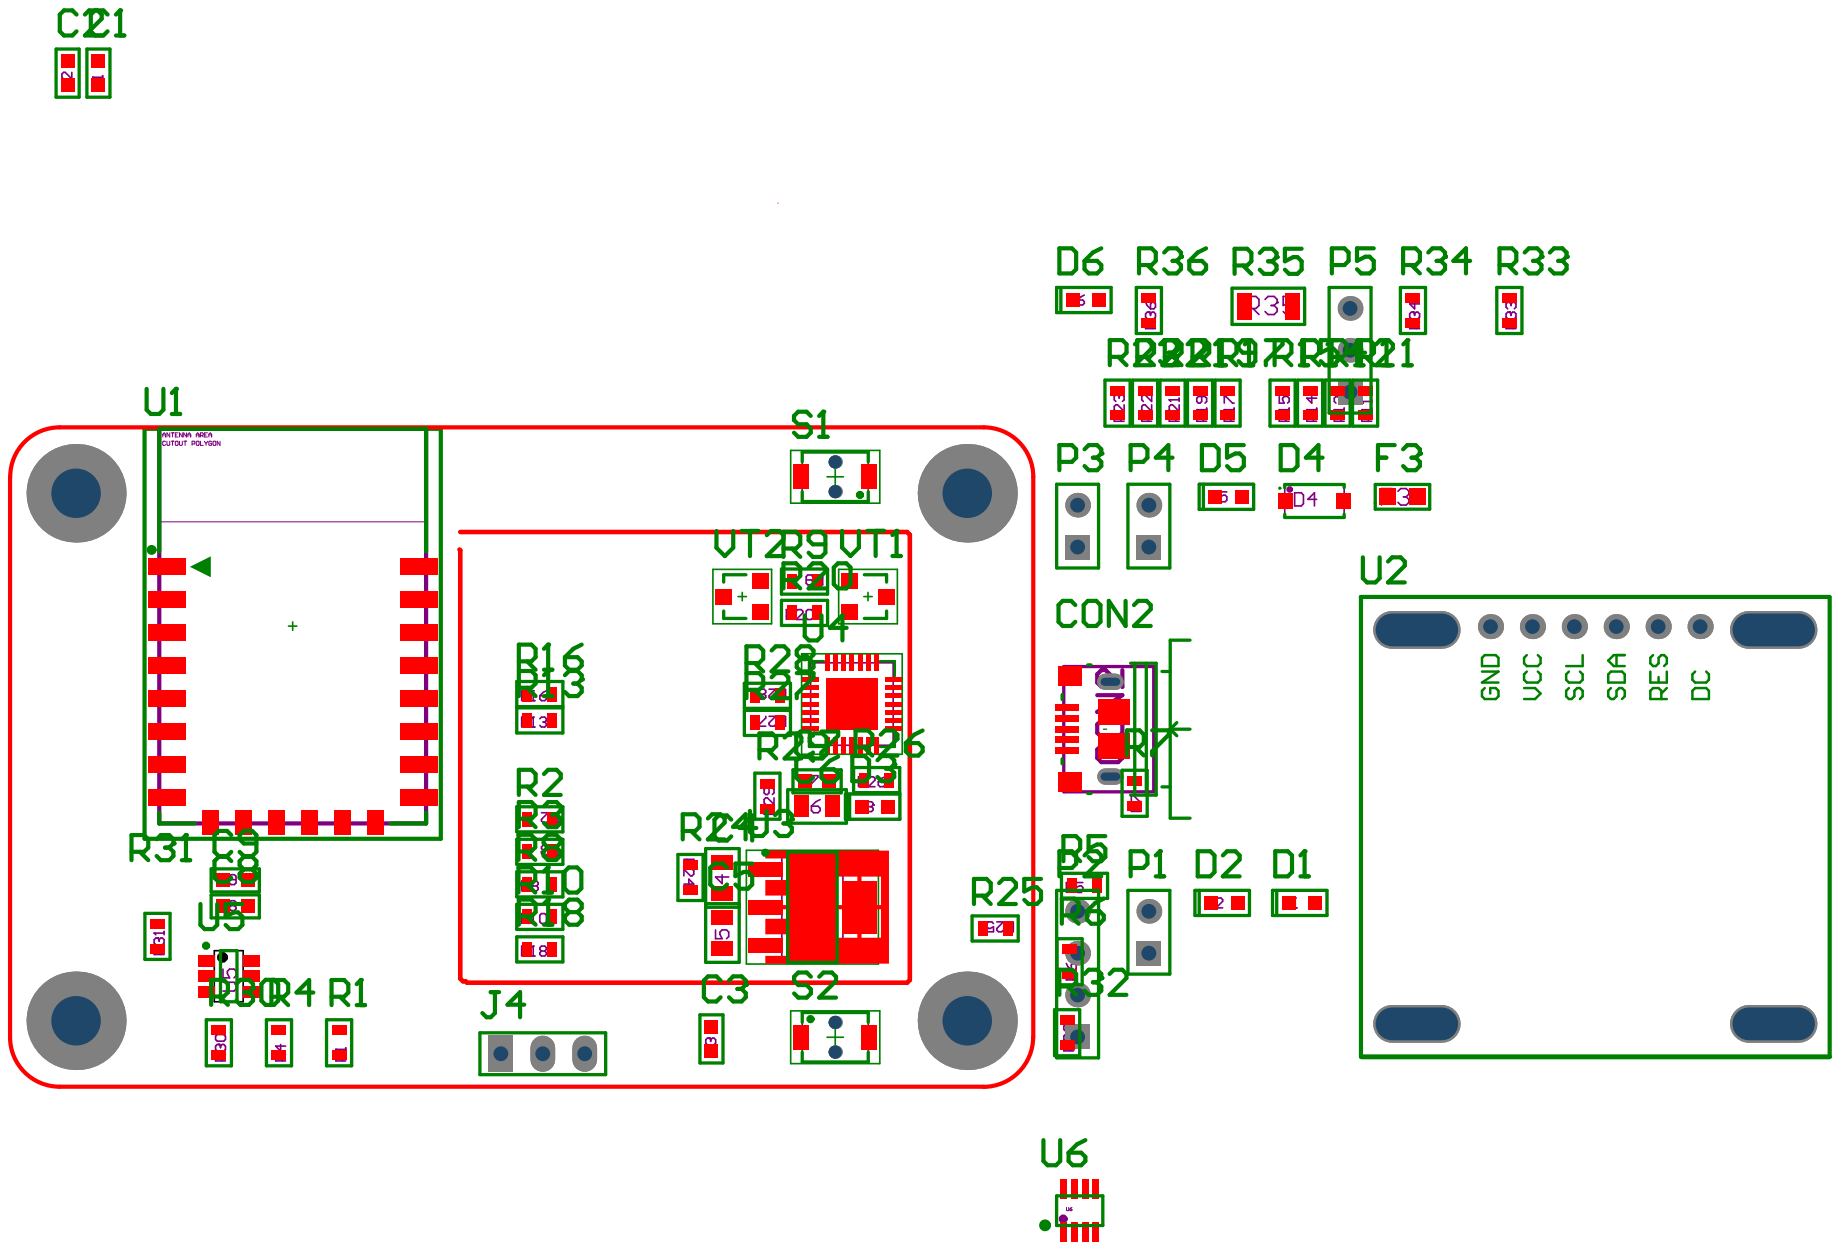
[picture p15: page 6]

# Board Stack Report

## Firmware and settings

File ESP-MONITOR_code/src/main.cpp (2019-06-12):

#include <ESP8266WiFi.h>
#include <WiFiClient.h>
#include <ESP8266WebServer.h>
#include <EEPROM.h>
#include <Wire.h>

#include <Adafruit_SSD1306.h>
#include <Adafruit_GFX.h>
#include <PubSubClient.h>
#include <INA219.h>

#include "setup/webpage.h"
#include "setup/currentmonitor.h"
#include "display/display.h"
#include "Ticker.h"

#define POWER_CYCLE (15)
#define PUBLISH_LED (12)
#define TEST_LED    (13)
#define BUILT_IN_LED (2)
#define USER_BUTTON (14)

const char *ssid = "ESP-MONITOR";           // AP SSID
const char *password = "ESP-MONITOR";       // AP Password
const char *mqtt_server = "192.168.13.121"; // IP of MQTT broker

// Declaration for an SSD1306 display connected to I2C (SDA, SCL pins)
#define OLED_RESET (16) // Reset pin for OLED, if not used set it to -1
Adafruit_SSD1306 display(128, 64, &Wire, OLED_RESET);

// WiFi globals
ESP8266WebServer server(80); // Specify port
WiFiClient client;
String Essid = ""; // EEPROM Network SSID
String Epass = ""; // EEPROM Network Password
String sssid = ""; // Read SSID From Web Page
String passs = ""; // Read Password From Web Page

 
// MQTT globals
PubSubClient Client(client);
String clientId = "ESP";            // String needed for callback and reconnect MQTT functions,
                                    // do not change it, otherwise you have to also change Node-Red code
#define SIZE (200)                  // Maximum size of receving buffer for UART
char recvbuffer[SIZE];              // Buffer for receving strings over UART
char mqttId[15];                    // Devices ID that will be copied into published messages
char formatedSerialData[SIZE];
char formatedCurrentData[120];

// INA219 globals
INA219 ina219;
#define CURRENT_ARRAY_SIZE (1000) //Number of samples that are sent over MQTT after being collected
#define VOLTAGE_ARRAY_SIZE (1000)
int currentArray[CURRENT_ARRAY_SIZE];
int voltageArray[VOLTAGE_ARRAY_SIZE];
int sampleNumber = 0;

// Erasing flash memory with USER button
Ticker flashErase;          //Ticker object for timer interrupt
int eraseCounter = 0;
uint8_t eraseFlag = 0;

void debounceUserButton()
{
    if (digitalRead(USER_BUTTON) == HIGH)
       eraseCounter++;
    else
       eraseCounter = 0;
    // When button is pressed for some time, set the eraseFlag, flash will be cleaned
    if(eraseCounter >= 300)
        eraseFlag = 1;
    else
        eraseFlag = 0;
}

// Function that is called every time when send message from Node-Red
void callback(char *topic, byte *payload, int length)
{
    // Function checks the topic of received topic and toggles power cycle pin depending on the message
    Serial.print("Message arrived [");
    Serial.print(topic);
    Serial.print("] ");
    for (int i = 0; i < length; i++)
    {
        Serial.print((char)payload[i]);
    }
    Serial.println();

    if (strcmp(topic, "PowerCycle") == 0)
    {
        // Switch on the LED if an 1 was received as first character
        if ((char)payload[0] == '1')
        {
            digitalWrite(POWER_CYCLE, HIGH);
            digitalWrite(BUILT_IN_LED, LOW);
        }
        else
        {
            digitalWrite(POWER_CYCLE, LOW); 
            digitalWrite(BUILT_IN_LED, HIGH);
        }
    }
}

// Reconnect function for MQTT connection
void reconnect(String clientId)
{
    // Loop until we're reconnected
    while (!client.connected())
    {
        // Attempt to connect
        Serial.print("Attempting MQTT connection...");
        if (Client.connect(clientId.c_str()))
        {
            Serial.println("connected");
            // Once connected, publish an announcement...
            Client.publish("Serial", "hello world");
            // ... and resubscribe
            Client.subscribe("PowerCycle");
        }
        else
        {
            Serial.print("failed, rc=");
            Serial.print(Client.state());
            Serial.println(" try again in 5 seconds");
            // Wait 5 seconds before retrying
            delay(5000);
        }
    }
}

// Function fills recvbuffer with received UART data
int receivedUartData()
{
    if (Serial.available() == 0)
        return 0;   // Buffer is empty, exit function
    else
    {
        while (Serial.available() > 0)
        {
            Serial.readBytesUntil('\r', recvbuffer, SIZE);  //Should be \r\n, with Arduino's Serial.println() function should work fine
        }
        
        //Serial.print(recvbuffer);

        // Flush buffer
        while (Serial.available() > 0)
        {
            Serial.read();
        }
        return 1;   // Buffer has some data, exit function
    }
}

void setup()
{
    Serial.begin(115200);
    EEPROM.begin(512);
    WiFi.mode(WIFI_AP_STA);
    Serial.println("Hello!");

    // Setup power cycle pin for INA219, led on esp module will serve as indicator
    pinMode(POWER_CYCLE, OUTPUT);
    digitalWrite(POWER_CYCLE, HIGH);
    pinMode(BUILT_IN_LED, OUTPUT);
    digitalWrite(BUILT_IN_LED, LOW);

    //Setup led for indicating publiching of current data over MQTT
    pinMode(PUBLISH_LED, OUTPUT);
    digitalWrite(PUBLISH_LED, LOW);

    //Test led
    pinMode(TEST_LED, OUTPUT);
    digitalWrite(TEST_LED, LOW);

    //User button setup for erasing flash
    pinMode(USER_BUTTON, INPUT);
    
    // Setup current monitor INA219
    setupMonitor();

    // Generate mqtt client name based of last 24 bits of MAC address
    // Copy mac address to char array mqttID for recognizing data sent from different devices
    clientId += WiFi.macAddress();
    clientId.remove(4, 9);
    clientId.toCharArray(mqttId, 15);

    // Initialize connection with OLED display
    initDisplay();

    // Greet user on display
    greetScreenDisplay();

    // Check EEPROM for past configuration
    checkingEepromDisplay();

    for (int i = 0; i < 32; ++i) //Reading SSID
    {
        Essid += char(EEPROM.read(i));
    }
    for (int i = 32; i < 96; ++i) //Reading Password
    {
        Epass += char(EEPROM.read(i));
    }

    // Check if old network is in flash
    if (EEPROM.read(0) == 0xFF)
    {
        // No old network found, initialize web server
        initWebServer(ssid, password);

        // Display instructions for connection
        instructConnDisplay();

        Serial.println("Reset me when ready!");
        while (1)
        {
            // Loop here to handle web requests, user should reset ESP
            server.handleClient();
        }
    }
    else
    {
        // Old network found
        display.clearDisplay();
        display.setCursor(0, 0);
        display.println(F("Network found:"));
        display.println(Essid);
        display.display();
        delay(1000);

        WiFi.begin(Essid.c_str(), Epass.c_str());
        display.print(F("Connecting"));
        display.display();
        delay(1000);

        // Trying to connect to it
        uint8_t attempt = 0;
        while (WiFi.status() != WL_CONNECTED)
        {
            display.print(F("."));
            display.display();
            delay(1000);

            if (attempt >= 10) // Timeout in 10 seconds
            {
                // Connection timeout reached, setup web server, user can change network or try again with reset
                WiFi.disconnect();
                delay(300);
                initWebServer(ssid, password);
                connTimeoutDisplay();

                while (1)
                {
                    // Loop here to handle web requests, user should reset ESP
                    server.handleClient();
                }
            }
            attempt += 1;
        }
        // Connected
        connectedDisplay(mqttId);

        // Connect to broker
        Client.setServer(mqtt_server, 1883);
        Client.setCallback(callback);
        flashErase.attach(0.01, debounceUserButton);    // Setup and run timer interrupt 
        Serial.println("Ready to listen!");
    }
}

void loop()
{
    if (!Client.connected())
        reconnect(clientId);

    if (!Client.loop())
        Client.connect(clientId.c_str());

    if (receivedUartData())
    {
        //When we receive data over UART we send it to MQTT broker
        display.clearDisplay();
        display.setCursor(0, 0);
        display.println(F("Last input received: "));
        display.println(recvbuffer);
        display.display();

        //Serial.print(recvbuffer);

        // Conectate device id with serial input
        strcpy(formatedSerialData, mqttId);
        strcat(formatedSerialData, " & ");
        strcat(formatedSerialData, recvbuffer);

        // Publish message to topic Serial
        Client.publish("Serial", formatedSerialData);
        memset(recvbuffer, 0, SIZE);
    }

    if (sampleNumber == CURRENT_ARRAY_SIZE)
    {
        /* When we fill our array with samples we calculate the max, min, avg and std values
        and we send them over MQTT. In current implementation there is no delay in main loop, 
        as we already need more than a second to collect all samples, get the values and send them over MQTT.
        If this rate of sending messages needs to be changed for any reason, we suggest adjust the size of 
        currentArray with macro CURRENT_ARRAY_SIZE and adding a delay at the end of main loop. */
        // Calculate max, min, avg, std values and save them to struct to struct
        struct mqttData currentData = updateData(currentArray, CURRENT_ARRAY_SIZE, CURRENT_DATA);
        struct mqttData voltageData = updateData(voltageArray, VOLTAGE_ARRAY_SIZE, VOLTAGE_DATA);

        // Conectate device id with current data, do not change this line, othwerwise you will have to fix parsing in Node-Red
        snprintf(formatedCurrentData, 120, "%s & %0.1f, %0.1f, %0.1f, %0.1f, %0.1f, %0.1f, %0.1f, %0.1f", mqttId, 
        currentData.maxValue, currentData.minValue, currentData.meanValue, currentData.stdValue,
        voltageData.maxValue, voltageData.minValue, voltageData.meanValue, voltageData.stdValue);

        // Publish message to topic Current
        Client.publish("CurrentVoltage", formatedCurrentData);

        // Flash led
        digitalWrite(PUBLISH_LED, HIGH);
        delay(10);
        digitalWrite(PUBLISH_LED, LOW);
        
        sampleNumber = 0;
    }
    else
    {
        currentArray[sampleNumber] = (int) (ina219.shuntCurrent() * 10000);     // We multiply with 1000 to get from A to mA,
                                                                                // and by another 10 to get rid of the floating point
                                                                                // so that currentArray can be int and not float

        voltageArray[sampleNumber] = (int) (ina219.busVoltage()*100);           // We multiply with 100 to get rid of the floating point
                                                                                // so that voltageArray can be int and not float
        sampleNumber++;
    }

    // In case that User button is being pressed for longer time the flash gets erased
    if (eraseFlag == 1)
    {
        flashErasedDisplay();
        // Erase Flash!
        EEPROM.write(0, 0xFF);
        EEPROM.end();
        while (1)
        {
        }
    }
}

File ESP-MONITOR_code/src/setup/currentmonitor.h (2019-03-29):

#pragma once

#include <Wire.h>
#include <Arduino.h>
#include <INA219.h>
#include <math.h>

// Here you can change parameters for current monitor INA219 
#define R_SHUNT (0.1f)        // Shunt resistor in omhs
#define V_SHUNT_MAX (0.320f)  // Max voltage drop over shunt resistor in volts
#define V_BUS_MAX (32.0f)     // Max bus voltage in volts
#define I_MAX_EXPECTED (1.5f) // Max expected current through shunt resistor in ampers

extern INA219 ina219;

// Struct needed to export data in string that will be send over mqtt
struct mqttData
{
  float minValue;
  float maxValue;
  float meanValue;
  float stdValue;
};

// Needed to differentiate between different equations used for calculating data
typedef enum {
  VOLTAGE_DATA = 0,
  CURRENT_DATA = 1,
}dataINA;

// Setup function, has to be called first as it configures and calibrates INA219. 
void setupMonitor();

// Helper functions to calculate values 
float max(int samples[], int size, dataINA select);
float min(int samples[], int size,  dataINA select);
float mean(int samples[], int size, dataINA select);
float stdValue(int samples[], float mean, int size, dataINA select);

// Main function that calls helper functions and uses correct version of them 
mqttData updateData(int samples[], int size, dataINA select);

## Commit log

2019-03-30 Added hardware files
    [05_CONN.SchDoc, Bill of Materials production v1.0-ESP-MONITOR.xlsx, ESP-MONITOR.PrjPCB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]
2019-06-12 Updated MQTT borker IP, powercycle pin is now High by default
